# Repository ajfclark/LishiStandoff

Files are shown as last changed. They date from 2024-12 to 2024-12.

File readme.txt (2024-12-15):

PRINTING NOTES

Ideally this part should be printed at .1mm layer height with 100% infill for best results.

But it should also work on a well tuned printer at .2mm layer height at 100% infill.

I use a .15mm layer height.

BACKGROUND

Much of the backstory of this part is shown in this video here...

   https://www.youtube.com/watch?v=Y023QVd8pvY&t=1714s

... at the 28:30 mark.  This is a tiny adapter to allow greater flexibility of use for Lishi brand 2-in-1 style decoder lockpick tools.  Lishi picks are made in different lengths for different sizes of lock.  However, due to their high cost, I thought it would be a good idea to help people adapt larger sized Lishi tools so that they work effectively in smaller locks, obviating the need to purchase additional expensive hardware.

This small collar fits over the blade of a Lishi pick to provide 4.2mm of standoff distance from the front face of the plug, which makes it suitable for use on Australian lockwood systems.

INSTALLATION

Deviant Ollam created a short guide video showing the best way to install this tool on a Lishi pick...

   https://www.youtube.com/watch?v=Z0uEKEhczAo

WHY DID YOU MAKE YOUR OWN VERSION AJ?

The above installation tip doesn't work for me with my printer and an LW5 lishi so... I rewrote it in openscad, added a bunch of paramaters so I could tweak it more, and then added a little ramp so it would sit neatly on my tool.

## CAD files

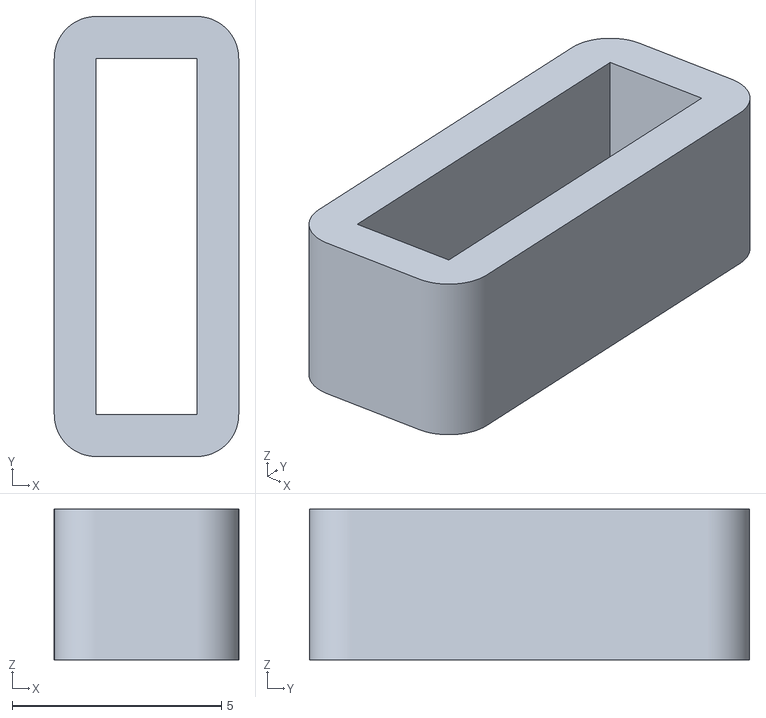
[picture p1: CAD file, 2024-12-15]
Lishi Standoff Spacer.schlage.stl
4.41 x 10.5 x 3.60

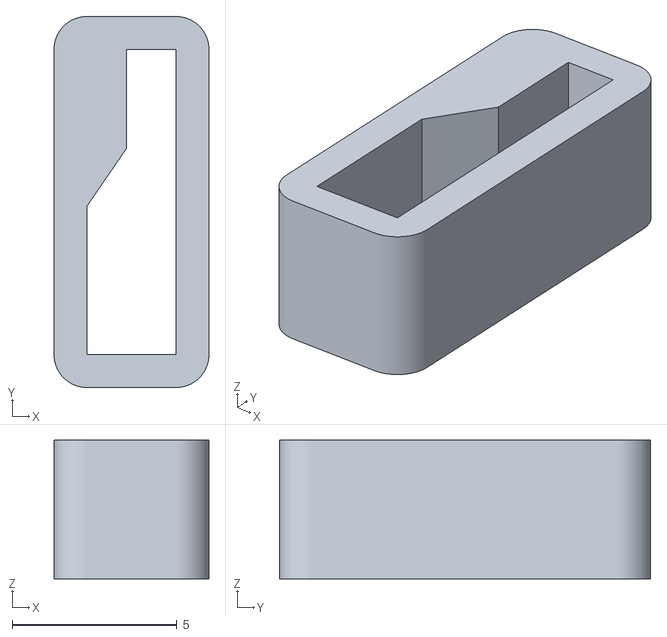
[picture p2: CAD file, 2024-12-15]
Lishi Standoff Spacer.LW5.stl
4.70 x 11.2 x 4.20

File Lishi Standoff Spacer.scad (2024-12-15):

/* [Tool Dimensions] */
// Blade height (at the shoulder)
bladeHeight=9.25; // 0.001
// How far down the keyway the angle should start
bladeUpperHeight=3.0; // 0.001
// Thickness of the blade at the top
bladeUpperThickness=1.5; // 0.001
// How far up the keyway the angle should start
bladeLowerHeight=4.5; // 0.001
// Thickness of the blade at the bottom
bladeLowerThickness=2.7; // 0.001
// The pin spacing - this will be the distance the standoff pushes the tool out
pinSpacing=4.20; // 0.001
/* [Printing/Rendering Options]*/
// How much material to use
collarWidth=1.0; // 0.01
// The resolution used to calculate curves - as a power of two
curveResolution=8; // [4:8]

$fn=pow(2,curveResolution);

linear_extrude(pinSpacing) {
	difference() {
		body(bladeHeight, bladeLowerThickness, collarWidth);
		inside(bladeHeight, bladeLowerHeight, bladeLowerThickness, bladeUpperHeight, bladeUpperThickness); 
	}
}

/* Functions */

module corners(x, y, radius) {
	for (i=[0:1]) {
		for (k=[0:1]) {
			mirror([i,0,0]) {
				mirror([0,k,0]) {
					corner(x, y, radius);
				}
			}
		}
	}
}

module corner(x, y, radius) {
	translate([x - radius/2, y - radius/2, 0]) {
		intersection() {
			square([radius, radius]);
			circle(radius);
		}
	}
}

module body(height, width, collarWidth) {
	x = (width + collarWidth) / 2;
	y = (height + collarWidth) / 2;
	
	square([width, height + 2 * collarWidth], center=true);
	square([width + 2 * collarWidth, height], center=true);
	corners(x, y, radius=collarWidth);
}

module inside(bladeHeight, bladeLowerHeight, bladeLowerThickness, bladeUpperHeight, bladeUpperThickness) {
	x = bladeLowerThickness / 2;
	y = bladeHeight / 2;
	polygon(
		[
			[-x,bladeLowerHeight-y],
			[-x,-y],
			[x,-y],
			[x,y],
			[x-bladeUpperThickness,y],
			[x-bladeUpperThickness,y-bladeUpperHeight]
		]
	);
}

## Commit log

2024-12-15 Initial scad of standoff with refined hole
    [Lishi Standoff Spacer.scad]
2024-12-15 Updated scad structure and parameters
    [Lishi Standoff Spacer.scad]
2024-12-15 Rendered new version of STL
    [Lishi Standoff Spacer.stl]
2024-12-15 Added JSON parameters for schlage and kwikset systems based on measurements from Deviant's original model
    [Lishi Standoff Spacer.scad]
2024-12-15 Added models for all current versions in the parameter file
    [Lishi Standoff Spacer.LW5.stl, Lishi Standoff Spacer.kwikset.stl, Lishi Standoff Spacer.schlage.stl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]
